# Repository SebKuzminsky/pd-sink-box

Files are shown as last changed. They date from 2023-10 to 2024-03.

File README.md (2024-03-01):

# Introduction

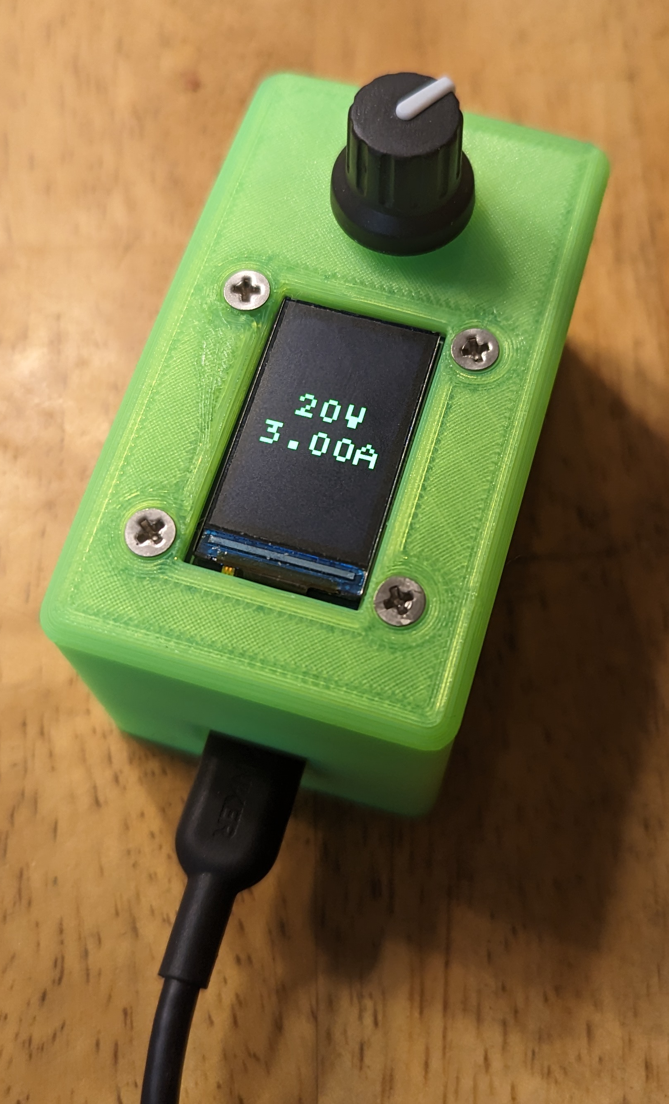
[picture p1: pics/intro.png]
overview picture


This device provides power from a USB PD source (such as a cheap modern
phone charger) to a pair of screw terminals, and lets the user select
the voltage and max current from among what the PD source offers.

USB PD sources typically offer one or more voltages (5V, 9V, 12V, 15V,
18V, and 20V), each with its own current limit.

menu picture

# Design

This device is based on the HUSB238 USB PD Sink chip and an RP2040
microcontroller (Raspberry Pi Pico).

The user interface is a small screen and a rotary-encoder/push-button
knob.  The UI shows the active power, and lets the user select among
the alternatives offered by the USB-PD Source.

The device also includes a Mini360 buck converter to power the 3.3V
control electronics from whatever voltage the USB PD source is currently
supplying.  The buck converter powers the Pico via its VSYS input
(protected by an 1N5817 Schottky diode).  The HUSB238 can't provide
power below 5V, so it does not need a boost converter.  This way you
can plug the Pico into a computer via USB for development/debugging and
"UI-over-serial", even while it's connected to a 20V USB-PD source.

The Pico talks I2C to the HUSB238.

The Pico talks SPI to the display.

## Bill of materials

HUSB238:
* <https://www.adafruit.com/product/5807>
* <https://en.hynetek.com/2421.html>

RP2040 (Raspberry Pi Pico, non-H variant, i.e. the one without pin
headers):
* <https://www.raspberrypi.com/products/raspberry-pi-pico/>

Mini360:
* <https://components101.com/modules/mini360-dc-dc-buck-converter-module>
* <https://www.ebay.com/itm/132416658988>

1N5817 Schottky diode

1.14 inch color LCD display module, 240x135:
* <https://www.waveshare.com/1.14inch-lcd-module.htm>
* <https://www.waveshare.com/wiki/1.14inch_LCD_Module>

Rotary/push-button knob:
* <https://www.adafruit.com/product/377>

Panel mount screw terminals:
* <https://www.ebay.com/itm/301753692259>
* <https://www.ebay.com/itm/302724734282>

Custom 3d printed enclosure (FCStd & STLs in this repo)

Misc fasteners (see below)

Misc hookup wire, mostly 24 AWG stranded or similar, plus a short length
of red & black in 18 AWG.

# Enclosure

The enclosure is 3d printed from the FreeCAD file in this repo.
The plastic parts include standoffs with holes that I drill to size and
tap M2.  This works surprisingly well.

The screen is mounted with #4-40 flat head screws because they're about
the right size and it's what I happened to have on hand, though maybe
M2.5 would have been more consistent.

## Design

The enclosure is designed to make the device easy to assemble and easy
to work on.  You can have all the the electronics assembled and mounted,
but have the case off so everything is visible and accessible (including
the micro-USB connector on the Pico used to flash the firmware).

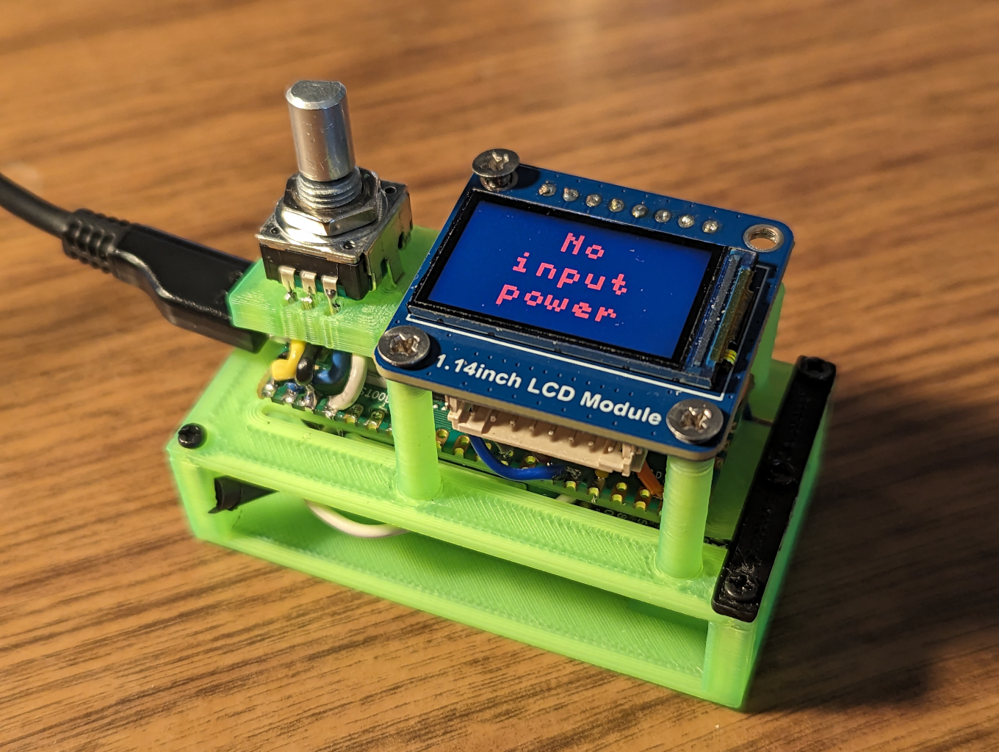
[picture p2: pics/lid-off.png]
lid off


The stack looks like this, starting at the bottom:

1.  The "base-plate" holds the HUSB238 and Mini360.  It has standoffs
    for the mid-plate.

2.  The "mid-plate" is mounted on the standoffs of the base-plate.
    It has standoffs for mounting the Pico, and standoffs for the screen.
    There are slots in the mid-plate that allow easy wiring from below
    (power from the Mini360 and I2C to the HUSB238).

3.  The "lid" or "case" is an inverted bowl that sits on top of the
    mid-plate.  The screen and the encoder knob both mount to the lid.
    The screws that attach the screen to the lid go into the standoffs
    on the mid-plate.  The encoder knob is panel-mounted to the lid with
    its own nut and washer.

You can unscrew the screen screws and the nut on the encoder knob and
take the lid off, and run the whole thing without the case.  You can
attach the screen to its standoffs on the mid-plate without the lid
(though the encoder knob has nowhere other than the lid to mount to,
so it's free floating in this configuration).

## Slicer

I configured my slicer to print 5 perimeters, to make the standoffs
stronger and more able to take a tap.

I configured my slicer to print the first layer at elevated temperatures,
to aid with print-bed adhesion and avoid corner lifting: 210°C nozzle,
65°C bed.  The rest of the part is printed at 190°C/60°C.  This is
working great.

## Fasteners

The enclosure is printed in pieces that screw together.  A clearance
hole in one part aligns with a matching threaded hole in another part,
and a screw holds them together.

Most fasteners are M2, except for the flat-heads that hold the lid on
the enclosure, those are M2.6.

M2 clearance holes should be 2.200 mm diameter, and are specified so in
the CAD model.  If your printer prints the holes undersized you may have
to drill them out with a #44 drill.

M2 threaded holes should be "pre-drilled" to 1.6 mm, and are specified
so in the CAD model.  If your printer prints the holes undersized you
may have to drill them out with a #52 drill.

M2.6 clearance holes are 2.7 mm, drill to size with a #36 drill.

M2.6 threaded holes are 2.26 mm, drill to size with a #43 drill.

I've tried two options for the threaded holes:

* M2 tapped holes and machine screws.  I tap gently by hand, being
  careful to not shear the fragile standoffs on the weak layer lines.
  This works well, but tapping all those holes is pretty labor intensive.

* M2 self-tapping "wood" screws.  This is much quicker, as the holes don't
  need to be tapped.  I just screw the screws in.  This also works well,
  but has the slight downside that the tapered points of the self-tapping
  screws take up some extra space.

screen to lid to mid-plate:
* 4x m2.6x6 self-tapping flat head

pico to mid-plate:
* 4x m2x4 self-tapping button head

mid-plate end-cap to mid-plate:
* 1x m2x4 self-tapping button head

mid-plate to base-plate:
* 4x m2x6 self-tapping button head

husb238 to base-plate:
* 2x m2x6 self-tapping button head

screw terminal to case:
* 2x m2x6 self-tapping button head

total:
* 4x m2.6x6 self-tapping flat head

* 5x m2x4 self-tapping button head

* 8x m2x6 self-tapping button head

# Assembly

## Enclosure prep

### M2 threaded holes

There are several holes that will take M2 threads:
* 6x on the Base-Plate
* 5x on the Mid-Plate
* 2x on the Lid

Drill these holes #52 (0.0635 inch, 1.613 mm).

FIXME: or slightly bigger?  The printed plastic standoffs are quite
fragile and the self-tapping screws apply enough force to
crack the standoffs on the layer lines.  1.6 mm (#52) or 1.75 mm (#50).
#51 (0.067 inch, 1.702 mm) works well.

### M2 clearance holes

There are several holes that need to pass M2 screws with clearance:
* 4x on the Mid-Plate
* 3x on the Mid-Plate End-Cap

Drill these #44 (0.086inch, 2.184mm).

### M2.6 threaded holes

There are several holes that need to take M2.6 threads:
* 4x screen standoffs on the Mid-Plate

Drill these holes #43 (0.089 inch, 2.261 mm).

FIXME: or slightly bigger?

### M2.6 clearance holes

Drill the M2.6 clearance holes in the lid #30 (0.129 inch, 3.264 mm).

## Base plate

Solder the I2C leads on the HUSB238.  Blue for SDA, yellow for SCK.
These are about 20 mm long.

Solder power leads to the HUSB238 board, one pair long to go to the
screw terminal and one pair short to go to the Mini360.

Solder the long power leads to the screw terminal, with the correct wire
lengths so the screw terminal will fit into its slot in the lid during
final assembly at the end.

Solder the short power leads from the HUSB238 to the input points on
the Mini360.

Solder a ground wire to the Mini360 OUT- pad.  Solder a Schottky diode to
the OUT+ pad, but *do not* connect it anywhere yet.  Note: the diode does
not fit through the slot in the mid-plate, so ensure there's an adequate
lead on the Pico side, and ensure that it's well covered by shrink tubing.

Mount the HUSB238 and Mini360 to the base-plate.

Connect the HUSB238 to power and adjust the pot on the Mini360 to get
about 3.3V after the diode (any voltage in the range ~2.3V to ~5.5V will
work well).

## Mid plate

Mount the mid-plate on its standoffs on the base-plate.  The standoffs
for the screen are on the same side of the device as the HUSB238.

Mount the Pico on its standoffs on the mid-plate.  The USB connector and
BOOTSEL button should be on the side that's *not* covered by the display.

Route the 3.3V and GND output lines from the Mini360 through the slots
in the mid-plate to pins 39 (VSYS) an 38 (GND) and solder them in place.

### Connect the HUSB238 to the Pico

Solder the I2C leads as follows:

```
Name | Pico pin | Direction | HUSB238 | Color
-----+----------+-----------+---------+-------
SDA  | 21       | <->       | SDA     | blue
SCL  | 22       |  ->       | SCL     | yellow
```

### Connect the rotary encoder knob to the Pico

Solder the leads as follows:

* Size the leads so that the top of the square body of the rotary
encoder (just under the washer & nut) is level with the tops of the
screen standoffs.

```
Pico GPIO | Pico Pin | Knob pin
----------+----------+-----------
GPIO 0    | 1        | A
GND       | 3        | C (center on 3-pin side)
GPIO 1    | 2        | B
----------+----------+-----------
GND       | 38       | either pin on 2-pin side
GPIO 2    | 4        | other pin on 2-pin side
----------+----------+-----------
```

* If the side with the three pins is facing you, with the shaft up,
then the pins are A, C, B.

* When stripping the wire to solder to the pico, very short exposed
conductors are sufficient, 2mm or so.

### Connect the display to the PICO

Temporarily mount the display on its standoffs.

Solder leads between Pico and the vias on the display board.  Bring the
wires up from the underside of the display board and clip any excess wire
on the top side flush with the board, to avoid interfering with the lid.

```
Pico Name          | Pico Pin | Direction | Display
-------------------+----------+-----------+--------
3.3V               | 36       |  ->       | VCC
GND                | 23       | <->       | GND
spi1 TX (GPIO 15)  | 20       |  ->       | DIN
spi1 SCK (GPIO 14) | 19       |  ->       | CLK
GPIO 12            | 16       |  ->       | CS
GPIO 11            | 15       |  ->       | D/C
GPIO 10            | 14       |  ->       | RST
PWM 4B (GPIO 9)    | 12       |  ->       | BL
```

Note: We solder individual wires rather than using the connector on the
screen because the connector comes out the side and interferes with the
case wall.

## Lid

Remove the temporary screws holding the screen on its standoffs.

Remove the nut & washer from the rotary encoder knob.

Slide the lid carefully over the main assembly.

* The rotary encoder knob should come up through its hole.  Attach it
with its washer and nut.

* Align the mounting holes in the screen with the holes in the lid and
in the standoffs, and screw it securely into place.

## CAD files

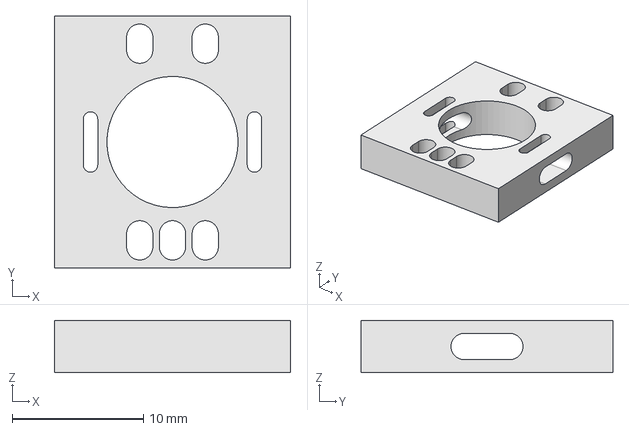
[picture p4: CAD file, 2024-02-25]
enclosure/encoder-pin-protector.FCStd
18.0 x 19.2 x 4.00 mm

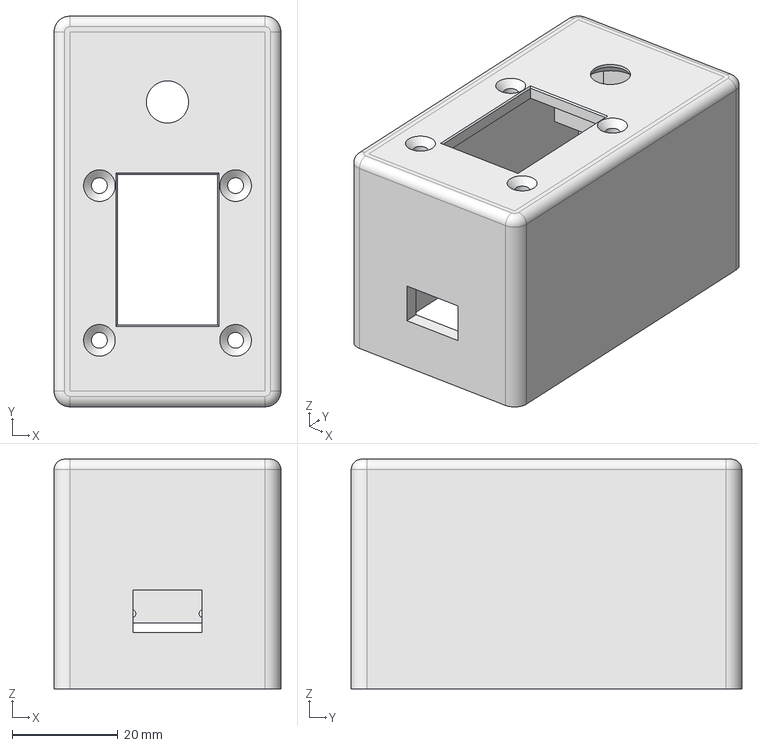
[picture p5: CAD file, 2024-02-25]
enclosure/enclosure.FCStd
43.0 x 74.0 x 43.5 mm

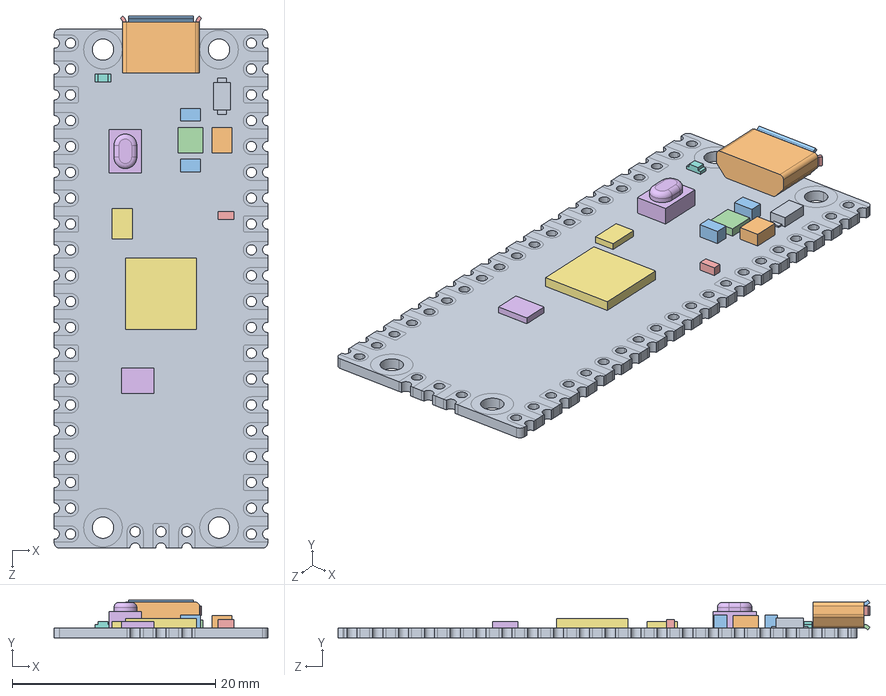
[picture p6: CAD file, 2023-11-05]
enclosure/Pico-R3.step
21.0 x 3.73 x 52.3 mm
PICO_REF_BOARD.STEP
PICO_REF_USB.STEP
PICO_REF_SWITCH.STEP
PICO_REF_MICROCONTROLLER.STEP
PICO_REF_LED.STEP
PICO_REF_ONSEMI.STEP
PICO_BOURNS.STEP
PICO_MURATA.STEP x 2
PICO_RICHTEK.STEP
PICO_DIODES.STEP
PICO_AEL.STEP
PICO_WINBOND.STEP

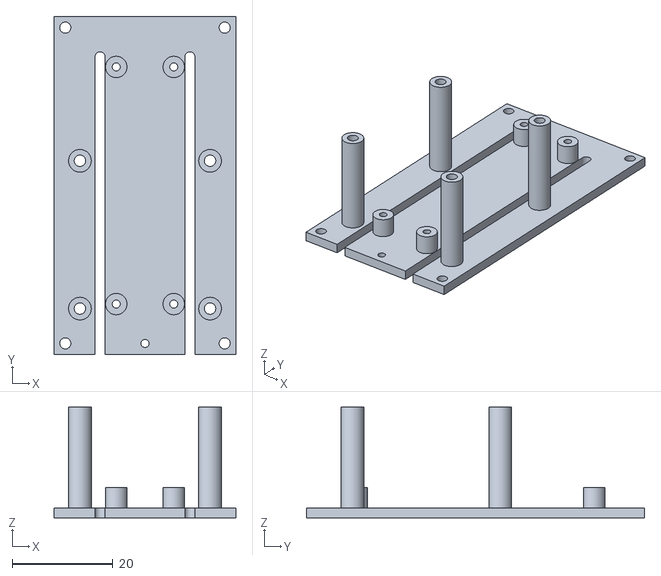
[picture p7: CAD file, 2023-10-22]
enclosure/enclosure-mid-plate.stl
36.0 x 67.0 x 22.0

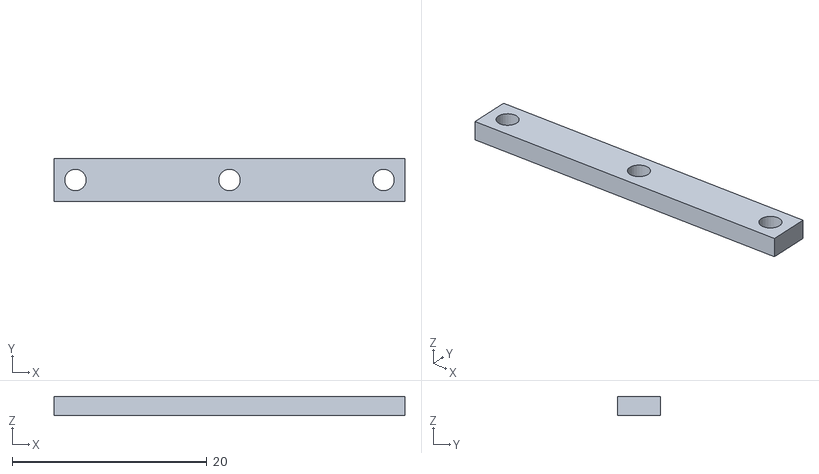
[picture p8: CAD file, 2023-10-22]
enclosure/enclosure-mid-plate-endcap.stl
36.0 x 4.40 x 2.00

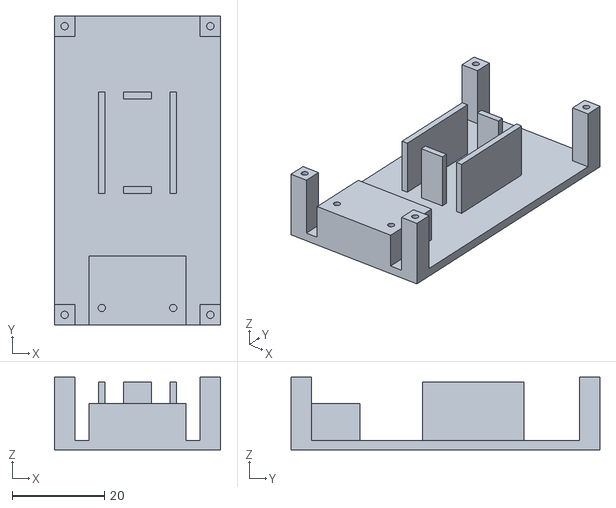
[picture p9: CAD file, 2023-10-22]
enclosure/enclosure-bottom-plate.stl
36.0 x 67.0 x 15.8

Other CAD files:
enclosure/enclosure-lid.stl
enclosure/encoder-pin-protector.stl

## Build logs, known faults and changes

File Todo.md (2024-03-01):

# Todo

FIXME: log scale for dimming the backlight

the husb238 crashes very often

    i2c errors talking with the husb238 :-(

Try switching from a Raspberry Pi Pico to a Waveshare RP2040 Zero, and
moving the screw terminal up one floor, and making the enclosure shorter.

Or try making my own board, optimized for this application.

    USB-C PD input connector / HUSB238 / RP2040 / Micro360 / Screw terminals

    maybe connectors for the knob & screen?

    extra USB connector for programming the RP2040, or can i share the
    USB-PD one?

    bootselect button near the USB connector, so it's reachable while
    the board is installed in the enclosure

    Maybe better to wait until a full PD/PPS solution

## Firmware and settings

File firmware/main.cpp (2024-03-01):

#include <cstdio>
#include <string.h>
#include <stdlib.h>
#include <wchar.h>

#include <hardware/i2c.h>
#include <hardware/spi.h>
#include <hardware/pwm.h>
#include <hardware/flash.h>
#include <hardware/sync.h>

#include <pico/stdlib.h>

#include <hagl_hal.h>
#include <hagl.h>
#include <font6x9.h>

#include <mipi_display.h>
#include <mipi_dcs.h>

#include "hagl_char_scaled.h"

#include "hmi.h"
#include "husb238.h"
#include "version-info.h"

#ifdef RASPBERRYPI_PICO_W
#include "pico/cyw43_arch.h"
#endif


//
// We store some config variables in flash and load them back in at
// boot time.
//
// The flash is memory-mapped into the RP2040 address space at XIP_BASE.
// We store our stuff at offset 256kB in the flash.
//

#define FLASH_OFFSET ((1024 + 512) * 1024)

// This is the data structure we store in flash.
static struct {
    uint8_t cookie;
    int backlight_duty_cycle;
    int screen_rotation_index;
    uint8_t checksum;
} flash_data;

static void write_flash(void) {
    // Cheesiest checksum ever.
    uint8_t checksum = 0;
    flash_data.cookie = 0x55;
    flash_data.checksum = 0;
    for (uint i = 0; i < sizeof(flash_data); ++i) {
        checksum ^= ((uint8_t *)(&flash_data))[i];
    }
    flash_data.checksum = checksum;

    uint32_t ints = save_and_disable_interrupts();

    // Erase one sector of the flash.
    flash_range_erase(FLASH_OFFSET, FLASH_SECTOR_SIZE);

    // Write our data to the flash.
    flash_range_program(FLASH_OFFSET, (uint8_t const *)(&flash_data), FLASH_PAGE_SIZE);

    restore_interrupts(ints);
}

static bool read_flash(void) {
    uint8_t const * flash_mem_ptr = (uint8_t const *)(XIP_BASE + FLASH_OFFSET);

    memcpy(&flash_data, flash_mem_ptr, sizeof(flash_data));

    uint8_t checksum = 0;
    for (uint i = 0; i < sizeof(flash_data); ++i) {
        checksum ^= ((uint8_t *)(&flash_data))[i];
    }

    if ((flash_data.cookie == 0x55) && (checksum == 0)) {
        // Valid flash.
        return true;
    }

    // Invalid flash, caller will initialize flash_data to sane defaults.
    return false;
}


static i2c_inst_t * i2c;
static int i2c_comm_errors = 0;

static hagl_backend_t *display;

static uint16_t display_width = MIPI_DISPLAY_WIDTH;
static uint16_t display_height = MIPI_DISPLAY_HEIGHT;

static int backlight_duty_cycle_max = 10*1000; // Highest possible value for duty cycle.
static int backlight_duty_cycle = 10*1000;     // Active value for duty cycle.
static int backlight_duty_cycle_delta = 1000;  // Duty cycle changes by this much for each knob detent.
static uint16_t backlight_pwm_slice;


typedef enum {
    WINDOW_MAIN,
    WINDOW_MENU,
    WINDOW_ROTATE,
    WINDOW_BACKLIGHT,
    WINDOW_INFO
} hmi_window_id_t;


//
// Main window
//

static uint32_t window_main_draw(void * void_context) {
    int r;
    int redraw_wait;

    int volts;
    float max_current;

    wchar_t str[40];
    int16_t x, y;

    uint8_t const * font = font6x9;
    int w=6, h=9;
    int scale=4;

    hagl_color_t text_color;

    hagl_clear(display);

    if (!husb238_connected(i2c)) {
        ++i2c_comm_errors;
        text_color = hagl_color(display, 255, 0, 0);

        r = swprintf(str, sizeof(str), L"No");
        x = (display->width - (r * w * scale))/2;
        y = (display->height / 2) - (1.5 * h * scale);
        hagl_put_text_scaled(display, str, x, y, text_color, scale, font);

        r = swprintf(str, sizeof(str), L"input");
        x = (display->width - (r * w * scale))/2;
        y = (display->height / 2) - (0.5 * h * scale);
        hagl_put_text_scaled(display, str, x, y, text_color, scale, font);

        r = swprintf(str, sizeof(str), L"power");
        x = (display->width - (r * w * scale))/2;
        y = (display->height / 2) + (0.5 * h * scale);
        hagl_put_text_scaled(display, str, x, y, text_color, scale, font);

        hagl_flush(display);

        // The Pico is running off its own USB power, but the HUSB238
        // does not have power.  Re-check and re-draw soon.
        return 100;
    }

    // Assuming we get good communication with the HUSB238, we won't
    // need to redraw again.
    redraw_wait = 0;

    r = husb238_get_contract(i2c, volts, max_current);
    if (r != PICO_OK) {
        ++i2c_comm_errors;
        printf("error reading PD contract from HUSB238\n");
        volts = -1;
        max_current = -1.0;
        redraw_wait = 100;  // Failed to read from HUSB238, re-try soon.
    }
    printf("(%d comm errors) PD contract: %dV %4.2fA\n", i2c_comm_errors, volts, max_current);

    if (volts > 0) {
        // Got a PD contract, show voltage and current limit in happy green text.
        text_color = hagl_color(display, 0, 255, 0);

        r = swprintf(str, sizeof(str), L"%dV", volts);
        x = (display->width - (r * w * scale))/2;
        y = (display->height / 2) - h * scale;
        hagl_put_text_scaled(display, str, x, y, text_color, scale, font);

        r = swprintf(str, sizeof(str), L"%04.2fA", max_current);
        x = (display->width - (r * w * scale))/2;
        y = (display->height / 2) + 2;
        hagl_put_text_scaled(display, str, x, y, text_color, scale, font6x9);

    } else {
        // No PD contract established, sad grayish text.
        text_color = hagl_color(display, 150, 150, 150);
        redraw_wait = 100;  // HUSB238 i2c comm error or HUSB238 reports "no contract", re-try soon.

        r = swprintf(str, sizeof(str), L"waiting");
        x = (display->width - (r * w * scale))/2;
        y = (display->height / 2) - h * scale;
        hagl_put_text_scaled(display, str, x, y, text_color, scale, font);

        r = swprintf(str, sizeof(str), L"for source");
        x = (display->width - (r * w * scale))/2;
        y = (display->height / 2) + 2;
        hagl_put_text_scaled(display, str, x, y, text_color, scale, font6x9);
    }

    hagl_flush(display);

    return redraw_wait;
}

static void window_main_any_interaction(void * void_context) {
    hmi_set_active_window(WINDOW_MENU);
}


//
// Menu window
//

typedef struct {
    wchar_t text[16];
    bool enabled;  // menu items that are !enabled are shown but not selectable
} menu_item_t;

typedef struct {
    menu_item_t * items;
    int selected_item;
    int num_items;
} menu_t;


typedef struct {
    husb238_pdo_t pdos[6];
    int current_pdo;       // this is the SRC_PDO identifier
    menu_t menu;
    int y_start;
} window_menu_context_t;

// This is how far from the screen edge the Menu starts or ends.
#define MENU_Y_MARGIN 5


static void * window_menu_init(void) {
    window_menu_context_t * context = (window_menu_context_t*)calloc(1, sizeof(window_menu_context_t));
    if (context == nullptr) {
        printf("out of memory\n");
        return nullptr;
    }

    context->y_start = MENU_Y_MARGIN;

    context->menu.num_items = 10;  // 6 PDOs, Rotate, Backlight, Info, Back
    context->menu.items = (menu_item_t*)calloc(context->menu.num_items, sizeof(menu_item_t));
    if (context->menu.items == nullptr) {
        printf("out of memory\n");
        return nullptr;
    }

    // The first 6 Menu items are the PDOs.  Because you can run this
    // device without USB-PD connected (by powering the Pico via its
    // own USB Micro-B connector) we re-read the PDOs each time the user
    // selects the Menu, and we re-sprintf the menu items based on the
    // max currents detected at that time (and set the enabled/disabled
    // state of each PDO).

    // The 7th Menu item is the Rotate screen.
    swprintf(
        context->menu.items[6].text,
        sizeof(context->menu.items[6].text),
        L"Rotate"
    );
    context->menu.items[6].enabled = true;

    // The 8th Menu item is the Backlight screen.
    swprintf(
        context->menu.items[7].text,
        sizeof(context->menu.items[7].text),
        L"Backlight"
    );
    context->menu.items[7].enabled = true;

    // The 9th Menu item is the Info screen.
    swprintf(
        context->menu.items[8].text,
        sizeof(context->menu.items[8].text),
        L"Info"
    );
    context->menu.items[8].enabled = true;

    // The 10th and final Menu item is Back, to go back to the main window.
    swprintf(
        context->menu.items[9].text,
        sizeof(context->menu.items[9].text),
        L"Back"
    );
    context->menu.items[9].enabled = true;

    return context;
}


//
// Draw the menu items, with different colors indicating whether each
// menu item is enabled (white, meaning it's available for the user
// to select) or disabled (gray, not selectable).  Also indicate the
// currently active PDO (if any) in green
//
// The menu is large enough and the screen is small enough that it
// doesn't always all fit.  In that case, show the parts of the menu
// near the selected item, and the rest is off-screen and invisible.
//

static uint32_t window_menu_draw(void * void_context) {
    window_menu_context_t * context = (window_menu_context_t*)void_context;

    uint8_t const * font = font6x9;
    int w=6, h=9;
    int scale=2;

    // This is the X position where we'll draw all the menu items.
    int x_pos = 5;

    hagl_clear(display);

    int r = husb238_get_current_pdo(i2c, &context->current_pdo);
    if (r != PICO_OK) {
        ++i2c_comm_errors;
    }

    // If we draw the menu in the same place as last time, will the
    // selected item be on the screen?  If not, we need to move the menu
    // up or down.
    int selected_item_y_pos = context->y_start + (context->menu.selected_item * h * scale);
    if (selected_item_y_pos < MENU_Y_MARGIN) {
        // Selected item is off the top of the screen, move the menu down.
        // To minimize visual disruption, we want the selected item to
        // be at the *top* of the screen.
        selected_item_y_pos = MENU_Y_MARGIN;
        context->y_start = selected_item_y_pos - (context->menu.selected_item * h * scale);
    } else if ((selected_item_y_pos + (h * scale) + MENU_Y_MARGIN) > display_height) {
        // Selected item is off the bottom of the screen, move the
        // menu up.  To minimize visual disruption, we want the selected
        // item to be at the *bottom* of the screen.
        selected_item_y_pos = display_height - MENU_Y_MARGIN - (h * scale);
        context->y_start = selected_item_y_pos - (context->menu.selected_item * h * scale);
    }

    // This is the Y position where we'll start drawing the first
    // menu item.  Each menu item below that is drawn one "character
    // height" lower.
    int y_pos = context->y_start;

    for (int i = 0; i < context->menu.num_items; ++i) {
        hagl_color_t white = hagl_color(display, 255, 255, 255);
        hagl_color_t gray = hagl_color(display, 150, 150, 150);
        hagl_color_t green = hagl_color(display, 0, 255, 0);

        hagl_color_t text_color;

        if (context->menu.items[i].enabled) {
            if ((i < 6) && (context->pdos[i].id == context->current_pdo)) {
                text_color = green;
            } else {
                text_color = white;
            }
        } else {
            text_color = gray;
        }

        if ((y_pos >= 0) && (y_pos < display_height - (h*scale))) {
            hagl_put_text_scaled(display, context->menu.items[i].text, x_pos, y_pos, text_color, scale, font);
            if (i == context->menu.selected_item) {
                hagl_color_t red = hagl_color(display, 255, 0, 0);
                wchar_t cursor[] = L"<<<";
                size_t len = wcslen(context->menu.items[i].text);
                hagl_put_text_scaled(display, cursor, x_pos+(len*w*scale), y_pos, red, scale, font);
            }
        }

        y_pos += h * scale;
    }

    hagl_flush(display);

    return 0;
}


// The Menu window was selected, re-read PDOs and regenerate the
// menu items enabled/disabled state.
static void window_menu_selected(void * void_context) {
    window_menu_context_t * context = (window_menu_context_t *)void_context;
    int r;

    r = husb238_get_pdos(i2c, context->pdos);
    if (r != PICO_OK) {
        ++i2c_comm_errors;
        printf("error reading PDOs\n");
    }

    // Update the first 6 menu items based on the PDOs offered by this
    // USB-PD Source.  All PDOs are displayed, but the ones not available
    // are disabled (grayed out and not selectable).
    for (int i = 0; i < 6; ++i) {
        r = swprintf(
            context->menu.items[i].text,
            sizeof(context->menu.items[i].text),
            L"%dV/%dA",
            (int)context->pdos[i].volts,
            (int)context->pdos[i].max_current
        );
        if (context->pdos[i].max_current > 0) {
            context->menu.items[i].enabled = true;
        } else {
            context->menu.items[i].enabled = false;
        }
    }

    // By default we select the currently active PDO.  If that's not
    // available we select the lowest-voltage available PDO.  If there
    // are no PDOs available, select the first non-PDO menu item.
    for (int i = 0; i < 6; ++i) {
        if (
            (context->pdos[i].id == context->current_pdo)
            && (context->menu.items[i].enabled)
        ) {
            context->menu.selected_item = i;
            return;
        }
    }
    for (int i = 0; i < context->menu.num_items; ++i) {
        if (context->menu.items[i].enabled) {
            context->menu.selected_item = i;
            return;
        }
    }
}


static void window_menu_cw(void * void_context) {
    window_menu_context_t * context = (window_menu_context_t*)void_context;

    context->menu.selected_item = (context->menu.selected_item + 1) % context->menu.num_items;
    while (! context->menu.items[context->menu.selected_item].enabled) {
        context->menu.selected_item = (context->menu.selected_item + 1) % context->menu.num_items;
    }
}


static void window_menu_ccw(void * void_context) {
    window_menu_context_t * context = (window_menu_context_t*)void_context;

    context->menu.selected_item -= 1;
    if (context->menu.selected_item == -1) {
        context->menu.selected_item = context->menu.num_items-1;
    }
    while (! context->menu.items[context->menu.selected_item].enabled) {
        context->menu.selected_item -= 1;
        if (context->menu.selected_item == -1) {
            context->menu.selected_item = context->menu.num_items-1;
        }
    }
}

static void window_menu_click(void * void_context) {
    window_menu_context_t * context = (window_menu_context_t*)void_context;

    if (context->menu.selected_item == 6) {
        hmi_set_active_window(WINDOW_ROTATE);
        return;
    } else if (context->menu.selected_item == 7) {
        hmi_set_active_window(WINDOW_BACKLIGHT);
        return;
    } else if (context->menu.selected_item == 8) {
        hmi_set_active_window(WINDOW_INFO);
        return;
    } else if (context->menu.selected_item == 9) {
        hmi_set_active_window(WINDOW_MAIN);
        return;
    }

    int r ;
    r = husb238_select_pdo(i2c, context->pdos[context->menu.selected_item].id);
    if (r != PICO_OK) {
        ++i2c_comm_errors;
    }
    r = husb238_dump_registers(i2c);
    if (r != PICO_OK) {
        ++i2c_comm_errors;
    }
    r = husb238_get_current_pdo(i2c, &context->current_pdo);
    if (r != PICO_OK) {
        ++i2c_comm_errors;
    }
    hmi_set_active_window(WINDOW_MAIN);
}


//
// Rotate window
//

typedef struct {
    struct {
        uint8_t dcs_address_mode;
        uint16_t width, height;
        int16_t x_offset, y_offset;
    } rotation_info[4];
    int rotation_index;
} window_rotate_context_t;

static void set_screen_rotation(window_rotate_context_t * c) {
    uint8_t mode = c->rotation_info[c->rotation_index].dcs_address_mode;

    hagl_clear(display);
    hagl_flush(display);

    mipi_display_ioctl(MIPI_DCS_SET_ADDRESS_MODE, &mode, 1);

    hagl_set_resolution(
        display,
        c->rotation_info[c->rotation_index].width,
        c->rotation_info[c->rotation_index].height
    );

    mipi_display_set_xy_offset(
        c->rotation_info[c->rotation_index].x_offset,
        c->rotation_info[c->rotation_index].y_offset
    );

    display_width = c->rotation_info[c->rotation_index].width;
    display_height = c->rotation_info[c->rotation_index].height;
}

static void * window_rotate_init(void) {
    window_rotate_context_t * c = (window_rotate_context_t *)calloc(1, sizeof(window_rotate_context_t));
    if (c == nullptr) {
        printf("out of memory\n");
        return nullptr;
    }

    // available constants
    // MIPI_DCS_ADDRESS_MODE_MIRROR_Y      0x80
    // MIPI_DCS_ADDRESS_MODE_MIRROR_X      0x40
    // MIPI_DCS_ADDRESS_MODE_SWAP_XY       0x20
    // MIPI_DCS_ADDRESS_MODE_BGR           0x08
    // MIPI_DCS_ADDRESS_MODE_RGB           0x00
    // MIPI_DCS_ADDRESS_MODE_FLIP_X        0x02
    // MIPI_DCS_ADDRESS_MODE_FLIP_Y        0x01

    // 0°, the native orientation of the screen
    c->rotation_info[0] = {
        .dcs_address_mode = 0x00,
        .width = MIPI_DISPLAY_WIDTH,
        .height = MIPI_DISPLAY_HEIGHT,
        .x_offset = MIPI_DISPLAY_OFFSET_X,
        .y_offset = MIPI_DISPLAY_OFFSET_Y,
    };

    // 90°
    c->rotation_info[1] = {
        .dcs_address_mode = MIPI_DCS_ADDRESS_MODE_SWAP_XY | MIPI_DCS_ADDRESS_MODE_MIRROR_X,
        .width = MIPI_DISPLAY_HEIGHT,
        .height = MIPI_DISPLAY_WIDTH,
        .x_offset = MIPI_DISPLAY_OFFSET_Y,
        .y_offset = MIPI_DISPLAY_OFFSET_X,
    };

    // 180°
    c->rotation_info[2] = {
        .dcs_address_mode = MIPI_DCS_ADDRESS_MODE_MIRROR_X | MIPI_DCS_ADDRESS_MODE_MIRROR_Y,
        .width = MIPI_DISPLAY_WIDTH,
        .height = MIPI_DISPLAY_HEIGHT,
        .x_offset = MIPI_DISPLAY_OFFSET_X,
        .y_offset = MIPI_DISPLAY_OFFSET_Y,
    };

    // 270°
    c->rotation_info[3] = {
        .dcs_address_mode = MIPI_DCS_ADDRESS_MODE_SWAP_XY | MIPI_DCS_ADDRESS_MODE_MIRROR_Y,
        .width = MIPI_DISPLAY_HEIGHT,
        .height = MIPI_DISPLAY_WIDTH,
        .x_offset = MIPI_DISPLAY_OFFSET_Y,
        .y_offset = MIPI_DISPLAY_OFFSET_X,
    };

    c->rotation_index = flash_data.screen_rotation_index;
    if (c->rotation_index < 0) {
        c->rotation_index = 0;
    } else if (c->rotation_index > 3) {
        c->rotation_index = 3;
    }

    set_screen_rotation(c);

    return c;
}

static uint32_t window_rotate_draw(void * void_context) {
    hagl_color_t white = hagl_color(display, 255, 255, 255);
    hagl_color_t red = hagl_color(display, 255, 0, 0);

    hagl_clear(display);

    hagl_draw_rectangle_xyxy(display, 0, 0, display_width-1, display_height-1, white);
    hagl_draw_rectangle_xyxy(display, 1, 1, display_width-2, display_height-2, white);
    hagl_draw_rectangle_xyxy(display, 2, 2, display_width-3, display_height-3, white);

    int r;
    wchar_t str[40];
    int16_t x, y;

    uint8_t const * font = font6x9;
    int w=6;
    int scale=4;

    r = swprintf(str, sizeof(str), L"Top");
    x = (display_width - (r * w * scale))/2;
    y = 5;
    hagl_put_text_scaled(display, str, x, y, red, scale, font);

    hagl_flush(display);
    return 0;
}

static void window_rotate_cw(void * void_context) {
    window_rotate_context_t * c = (window_rotate_context_t *)void_context;
    c->rotation_index = (c->rotation_index + 1) % 4;
    set_screen_rotation(c);
}

static void window_rotate_ccw(void * void_context) {
    window_rotate_context_t * c = (window_rotate_context_t *)void_context;
    c->rotation_index = c->rotation_index - 1;
    if (c->rotation_index == -1) c->rotation_index = 3;
    set_screen_rotation(c);
}

static void window_rotate_click(void * void_context) {
    window_rotate_context_t * c = (window_rotate_context_t *)void_context;
    flash_data.screen_rotation_index = c->rotation_index;
    write_flash();  // remember which screen orientation the user likes
    hmi_set_active_window(WINDOW_MAIN);
}


//
// Backlight window
//
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
int main() {
    stdio_init_all();
    // sleep_ms(3000);

    if (!read_flash()) {
        // Invalid flash, initialize to sane defaults.
        flash_data.backlight_duty_cycle = backlight_duty_cycle_max;
        flash_data.screen_rotation_index = 0;
    }

    backlight_duty_cycle = flash_data.backlight_duty_cycle;
    if (backlight_duty_cycle > backlight_duty_cycle_max) {
        backlight_duty_cycle = backlight_duty_cycle_max;
    } else if (backlight_duty_cycle < 0) {
        backlight_duty_cycle = 0;
    }

    display = hagl_init();

    // PWM control of backlight.
    gpio_set_function(MIPI_DISPLAY_PIN_BL, GPIO_FUNC_PWM);
    backlight_pwm_slice = pwm_gpio_to_slice_num(MIPI_DISPLAY_PIN_BL);
    pwm_set_wrap(backlight_pwm_slice, backlight_duty_cycle_max);
    // PWM channel A is not used.
    pwm_set_chan_level(backlight_pwm_slice, PWM_CHAN_B, backlight_duty_cycle);
    pwm_set_enabled(backlight_pwm_slice, true);

#if defined RASPBERRYPI_PICO_W
    if (cyw43_arch_init()) {
        printf("failed to initialise\n");
        return 1;
    }
    printf("cyw43_arch_init\n");
#endif

    // printf("\x1b[2J");  // VT100: clear screen
    printf("booted\n");

    //
    // Initialize i2c.
    //

    const uint sda_gpio = 16;  // pin 21
    const uint scl_gpio = 17;  // pin 22

    i2c = i2c0;
    i2c_init(i2c, 100*1000);  // run i2c at 100 kHz

    // Initialize I2C pins
    gpio_set_function(sda_gpio, GPIO_FUNC_I2C);
    gpio_set_function(scl_gpio, GPIO_FUNC_I2C);

    gpio_pull_up(sda_gpio);
    gpio_pull_up(scl_gpio);


    //
    // Initialize the HMI.
    //

    hmi_init(windows);


    //
    // And go!
    //

    hmi_run();
}

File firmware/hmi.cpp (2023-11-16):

#include "pico/time.h"

#include "hmi.h"
#include "quadrature_encoder.pio.h"
#include "button.pio.h"


static hmi_window_t * hmi_windows;
static int hmi_active_window;


void hmi_init(hmi_window_t * windows) {
    hmi_windows = windows;

    uint const encoder_gpio_a = 0;
    pio_add_program_at_offset(pio1, &quadrature_encoder_program, 0);
    quadrature_encoder_program_init(pio1, encoder_gpio_a, 0);

    uint const button_gpio = 2;
    pio_add_program_at_offset(pio0, &button_program, 0);
    button_init(pio0, 0, button_gpio);

    for (int i = 0; hmi_windows[i].id != -1; ++i) {
        if (hmi_windows[i].init != nullptr) {
            hmi_windows[i].context = hmi_windows[i].init();
        }
    }

    hmi_set_active_window(0);
}


void hmi_set_active_window(int id) {
    hmi_active_window = id;
    if (hmi_windows[id].selected != nullptr) {
        hmi_windows[id].selected(hmi_windows[id].context);
    }
}


void hmi_run(void) {
    bool need_redraw = true;
    absolute_time_t next_redraw = at_the_end_of_time;

    int new_count, delta;
    int old_count = quadrature_encoder_get_count();

    while (true) {
        if (!is_at_the_end_of_time(next_redraw)) {
            if (absolute_time_diff_us(get_absolute_time(), next_redraw) < 0) {
                need_redraw = true;
            }
        }
        if (need_redraw) {
            uint32_t ms_until_redraw;
            need_redraw = false;
            ms_until_redraw = hmi_windows[hmi_active_window].draw(hmi_windows[hmi_active_window].context);
            if (ms_until_redraw == 0) {
                next_redraw = at_the_end_of_time;
            } else {
                next_redraw = make_timeout_time_ms(ms_until_redraw);
            }
        }

        new_count = quadrature_encoder_get_count();
        delta = new_count - old_count;
        if (delta >= 4) {
            if (hmi_windows[hmi_active_window].event_ccw != nullptr) {
                hmi_windows[hmi_active_window].event_ccw(hmi_windows[hmi_active_window].context);
                need_redraw = true;
            }
            old_count = new_count;
        } else if (delta <= -4) {
            if (hmi_windows[hmi_active_window].event_cw != nullptr) {
                hmi_windows[hmi_active_window].event_cw(hmi_windows[hmi_active_window].context);
                need_redraw = true;
            }
            old_count = new_count;
        }

        uint32_t button_state;
        if (button_get_state(button_state)) {
            if (button_state == 0) {
                if (hmi_windows[hmi_active_window].event_click != nullptr) {
                    hmi_windows[hmi_active_window].event_click(hmi_windows[hmi_active_window].context);
                    need_redraw = true;
                }
            }
        }
    }
}

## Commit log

2023-10-22 initial import from private repo
    [enclosure-bottom-plate.stl, enclosure-lid.stl, enclosure-mid-plate-endcap.stl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]
2023-10-22 enclosure: make the lid slightly taller
    [enclosure-lid.stl, enclosure-mid-plate.stl, enclosure.FCStd]
2023-10-22 todo: interference between screen wires and case
2023-10-22 make the wiring between the display and the Pico more compact
    The connector comes out the side of the display board and interferes
    with the case.
2023-10-23 switch from HAGL's pixel doubling to scaled text
    It just seems simpler to think about.
2023-10-23 enclosure lid: make encoder cage only as tall as needed
    [enclosure-lid.stl, enclosure.FCStd]
2023-10-23 add a small part to protect the pins of the encoder knob
    [encoder-pin-protector.FCStd, encoder-pin-protector.stl]
2023-10-24 better assembly instructions for rotary encoder knob
2023-10-25 todo: a way to improve wiring maybe
2023-10-26 README: minor Assembly improvements
2023-10-26 change GPIOs used for screen
    This makes assembly easier.
2023-10-26 rebuild firmware with new screen wiring
2023-10-27 cmake: require pico-sdk 1.5.1 or newer
2023-10-27 rename "main menu" to just "menu" because that's the only one there is
    And because it's less finger strain.
2023-10-27 simplify menu display, don't print PDOs to stdout
2023-10-27 remove more debug prints from the menu window
2023-10-27 try running i2c to the husb238 slower
    100 kHz instead of 400 kHz, hoping this resolves the occasional
    communication glitches i'm seeing.
    [main.cpp]
2023-10-27 improve menu "selected item" handling
    This makes it more robust when i plug and unplug the HUSB238, while
    powering the Pico via its own micro-USB connector.
2023-10-28 todo: work around i2c problems somehow
2023-10-28 improve assembly instructions
2023-11-05 enclosure: switch to the official Raspberry Pi Pico STEP model
    [Pico-R3.step, enclosure.FCStd]
2023-11-05 track i2c comm errors better
    [main.cpp]
2023-11-05 rebuild firmware with i2c retries to the HUSB238 & github url on Info screen
2023-11-06 enclosure: extend the screw terminal window in the lid all the way down
    This way i can solder the screw terminal to the husb238, slide the lid
    down over it, and screw the screw terminal base to the lid. Much easier
    than dealing with spade terminals and stiff power wires that need to
    extend out of the old window in the lid and then compress into the case.
    [enclosure-lid.stl, enclosure.FCStd]
2023-11-08 firmware: disable uart stdio, no need to waste those pins
2023-11-16 bump rp2040-rotary-encoder submodule
    This picks up the PIO-based quadrature encoder.
2023-11-16 rebuild firmware with PIO-based quadrature encoder
2024-02-21 README: clarify the version of the Pico to use
2024-02-25 enclosure: chamfer inside of rotary knob shaft hole & cover the unused part of the display
    [enclosure-lid.stl, enclosure.FCStd]
2024-02-25 thicker covering over the display
    [enclosure-lid.stl, enclosure.FCStd]
2024-02-25 better encoder pin protector
    [encoder-pin-protector.FCStd, encoder-pin-protector.stl]
2024-03-01 bump rp2040-husb238 submodule to pick up improved i2c stress testing
2024-03-01 README: improve fasteners to speed up assembly
2024-03-01 README: add a note about screw terminal assembly
